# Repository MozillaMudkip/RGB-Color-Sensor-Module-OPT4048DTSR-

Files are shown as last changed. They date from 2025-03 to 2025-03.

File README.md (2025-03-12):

# RGB-Color-Sensor-Module-OPT4048DTSR-
Color Sensor Schematics, PCB and Code

This repository contains a collection of files that detail the creation of a RGB Color Sensor.

This color sensor module utilizes an OPT4048DTSR from Texas Instruments. This sensor is a high speed, high precision tristimulus XYZ color sensor which is able to perform high precision color to light digital conversion over an I2C interface. It is able to measure 4 channels, 3 of which match and recognize the CIE tristimulus spectra with the 4th being a wide band spectral responce. This sensor is paired with an LTW-C191TS5 from Lite-On to provide sufficient ambient white light so the OPT4048DTSR can measure color values from reflected light of the object to be sorted. This schematic and PCB was created in Altium Designer.

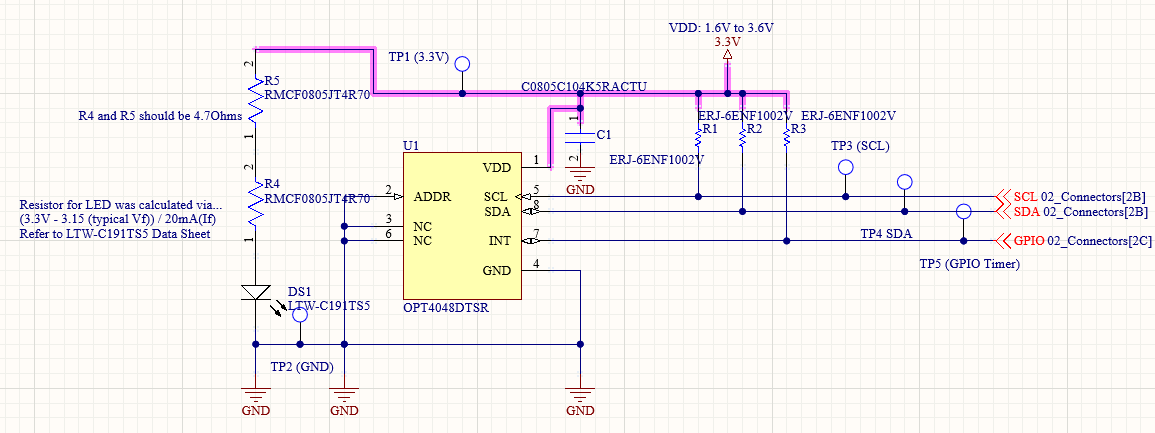
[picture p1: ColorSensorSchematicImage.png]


This particular sensor module was created to be a part of an automatic sorter, built as my Engineering Capstone Design project. Particularly, this sensor will be a part of the primary sensor array which, paired with an inductive sensor and an OpenCV camera system, will be able to look at an input object and determine aspects relating to its color, shape and material. The sorter will then sort the object with parameters specified by the user into one of many containers. 

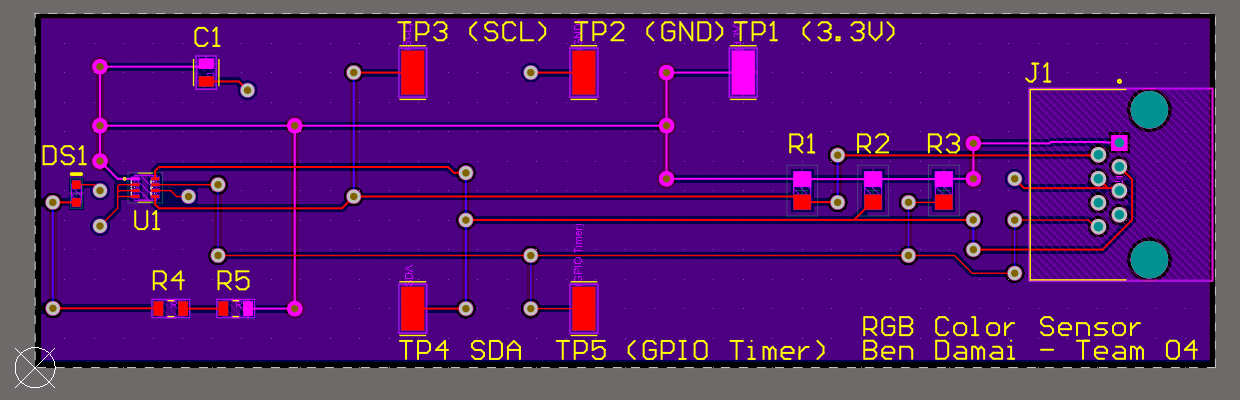
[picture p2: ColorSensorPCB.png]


The OPT4048DTSR and LED system takes in just a 3.3V input for power. Please note that the sensor has a minimum open air voltage range from 1.6V to 3.6V. 3.3V proved to be a convenient value for us as we use a 3.3 voltage source in numerous other portions of out project. For more information, please refer to the OPT4048DTSR datasheet which gives more specific allowances and typical setup and application. *Note to myself and others* - This partcular LED has a dot on the NEGATIVE side of the LED and not the positive. Caused me some issues while soldering and testing!

https://www.ti.com/lit/ds/symlink/opt4048.pdf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

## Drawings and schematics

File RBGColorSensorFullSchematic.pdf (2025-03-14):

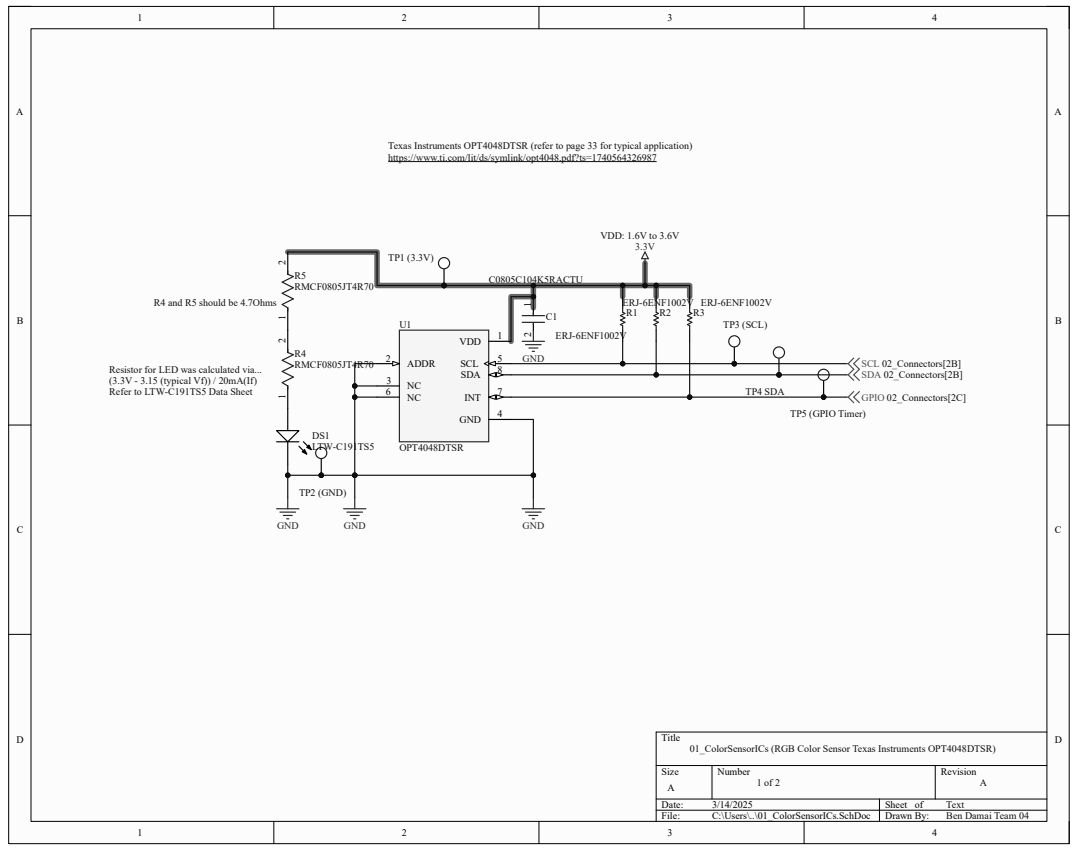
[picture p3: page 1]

Texas Instruments OPT4048DTSR (refer to page 33 for typical application)
https://www.ti.com/lit/ds/symlink/opt4048.pdf?ts=1740564326987

Resistor for LED was calculated via...
(3.3V - 3.15 (typical Vf)) / 20mA(If)

Title
01_ColorSensorICs (RGB Color Sensor Texas Instruments OPT4048DTSR)

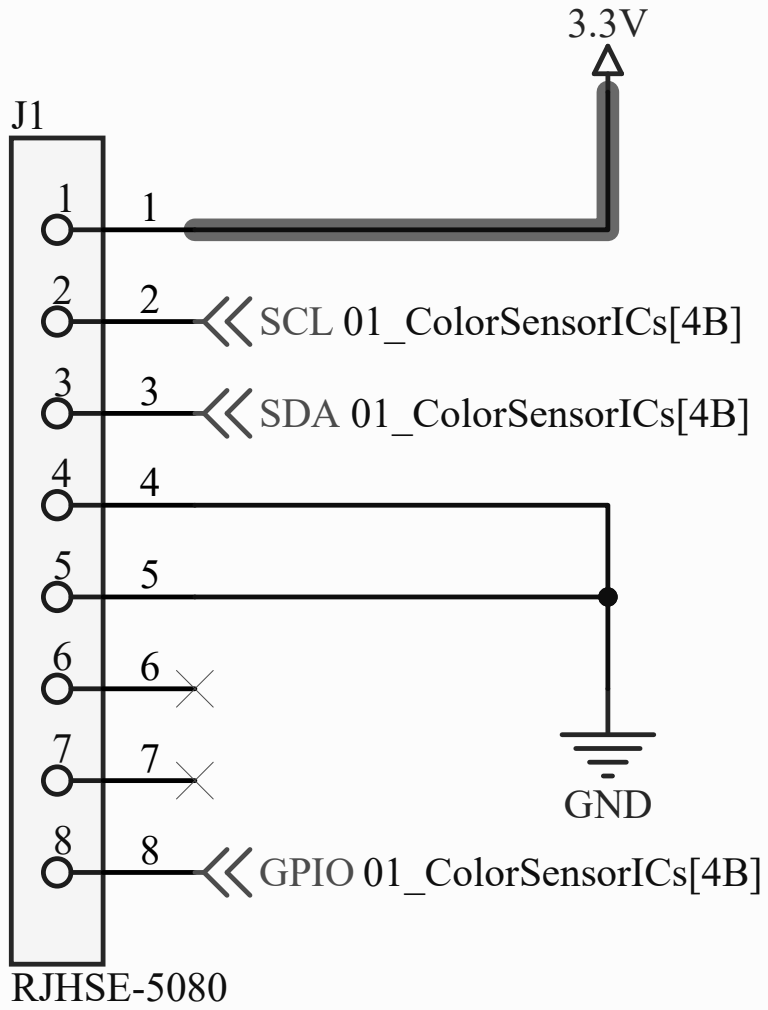
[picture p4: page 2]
Title; Size; Number; Revision; Date:; Sheet of; File:; C:\Users\..\02_Connectors.SchDoc; Drawn By:; 02_Connectors; Ben Damai Team 04; Text; RJHSE-5080; SCL 01_ColorSensorICs[4B]; SDA 01_ColorSensorICs[4B]; GPIO 01_ColorSensorICs[4B]; GND

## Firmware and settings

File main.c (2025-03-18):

#include "main.h"
#include "i2c.h"
#include "source/app_hw/task_console.h"
#include "source/app_hw/task_color_sensor.h"

int main(void) {
    cy_rslt_t rslt;
    rslt = cybsp_init();
    CY_ASSERT(rslt == CY_RSLT_SUCCESS);
    __enable_irq();

    i2c_init();
    /* Initialize FreeRTOS tasks */
    task_console_init();
    /* Initialize color sensor task */
    task_color_sensor_init();  
    /* Start scheduler to operate task functionality */ 
    vTaskStartScheduler();

    for (;;) { }
}

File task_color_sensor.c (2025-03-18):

#include "task_color_sensor.h"

/* Define I2C SDA and SCL pins */
#define COLOR_SENSOR_SDA    P9_0  
#define COLOR_SENSOR_SCL    P9_1 

#define OPT4048_I2C_ADDR  0x44  // I2C address with ADDR tied to GND (considered the default for this sensor)
#define OPT4048_REG_DATA  0x00  // Register to read color data
#define OPT4048_REG_CONFIG 0x0A // Sensor configuration register
/* FreeRTOS queue to send color data */
QueueHandle_t q_color_data;

static bool color_sensor_write_config(void) {
    uint8_t config_data[3] = {0x0A, 0x32, 0x38};  //Power on sensor and put into continuous operation
    uint8_t read_data[2];
    cy_rslt_t result;

    xSemaphoreTake(Semaphore_I2C, portMAX_DELAY); // Take I2C semaphore
    // Write to the configuration register
    result = cyhal_i2c_master_write(&i2c_master_obj, OPT4048_I2C_ADDR, config_data, 3, 0, true);
    //Delay to give sensor time to get ready for a read
    vTaskDelay(pdMS_TO_TICKS(500));
    //Read data from configuration register (for checking on oscilloscope)
    result = cyhal_i2c_master_read(&i2c_master_obj, OPT4048_I2C_ADDR, read_data, 2, 0, true);
    xSemaphoreGive(Semaphore_I2C); // Release I2C semaphore
    //Print out failure if we're given a failing read or write response
    if (result != CY_RSLT_SUCCESS) {
        task_print("Failed to write configuration register: 0x%04X\n", result); 
        return false;
    }
    return true;
}
/* Function to read from OPT4048 */
static bool color_sensor_read(uint8_t reg, uint8_t *data, uint8_t len) {     
    cy_rslt_t result;
    xSemaphoreTake(Semaphore_I2C, portMAX_DELAY); //Gain control of I2C bus

    //Write register address of the sensor
    result = cyhal_i2c_master_write(&i2c_master_obj, OPT4048_I2C_ADDR, &reg, 1, 0, true);   
    if (result != CY_RSLT_SUCCESS){
        xSemaphoreGive(Semaphore_I2C); //Return I2C bus on failure
        return false;
    }
    vTaskDelay(pdMS_TO_TICKS(500));
    //Read the data from the sensor
    result = cyhal_i2c_master_read(&i2c_master_obj, OPT4048_I2C_ADDR, data, len, 0, true);
    xSemaphoreGive(Semaphore_I2C); //Return I2C bus
    return (result == CY_RSLT_SUCCESS);
}

/* Color Sensor Task */
static void task_color_sensor(void *param) {
    /* Initialize the sensor by writing to the configuration register */
    if (!color_sensor_write_config()) {
        task_print("Failed to initialize OPT4048 sensor. Check I2C communication.\n");
        return; // Exit if initialization fails
    }
    
    while (1) {
        /* Wait before next read, avoids reading before sensor is ready */
        vTaskDelay(pdMS_TO_TICKS(1000));
    }
}

/* CLI Handler for 'colorsensor' command */
static BaseType_t cli_handler_colorsensor(
    char *pcWriteBuffer,
    size_t xWriteBufferLen,
    const char *pcCommandString)
{
    const char *pcParameter;
    BaseType_t xParameterStringLength, xReturn;
    color_data_t color_values;
    uint8_t raw_data[8];

    /* Get parameter string */
    pcParameter = FreeRTOS_CLIGetParameter(
        pcCommandString, 1, &xParameterStringLength);
    configASSERT(pcParameter);

    /* If we recieve the print command from the serial monitor... */
    if (strncmp(pcParameter, "print", xParameterStringLength) == 0) {
        //Read color sensor data 
        if (color_sensor_read(OPT4048_REG_DATA, raw_data, 8)) {    
            uint16_t x = (raw_data[0] << 8) | raw_data[1];
            uint16_t y = (raw_data[2] << 8) | raw_data[3];
            uint16_t z = (raw_data[4] << 8) | raw_data[5];
            uint16_t w = (raw_data[6] << 8) | raw_data[7];

            //Update color values
            color_values.red = x;
            color_values.green = y;
            color_values.blue = z;
            color_values.clear = w;

            /* Send data to queue */
            xQueueSend(q_color_data, &color_values, portMAX_DELAY);

            vTaskDelay(pdMS_TO_TICKS(500));
            /* Print out color data to serial monitor */
            task_print("X: %u, Y: %u, Z: %u, W: %u\n",
                       color_values.red, color_values.green,
                       color_values.blue, color_values.clear);
        }
    } 
    //In the event of any other input, give correct usage
    else {
        snprintf(pcWriteBuffer, xWriteBufferLen, "Invalid command. Use 'colorsensor print'.\n");
        xReturn = pdFALSE;
        return xReturn;
    }
    xReturn = pdFALSE;
    return xReturn;
}

/* The CLI command definition for the color sensor 
 User types in "colorsensor print" into serial monitor 
 to recieve printout of most recent color reading */
static const CLI_Command_Definition_t xColorSensor =
    {
        "colorsensor",
        "\r\ncolorsensor <print>\r\n Controls color sensor output.\r\n",
        cli_handler_colorsensor,
        1
    };

/* Initialization function for color sensor */
void task_color_sensor_init(void) {
    cy_rslt_t rslt;

    /* Create queue for color data */
    q_color_data = xQueueCreate(5, sizeof(color_data_t));
    configASSERT(q_color_data != NULL);

    /* Register CLI command */
    FreeRTOS_CLIRegisterCommand(&xColorSensor);
    
    /* Create FreeRTOS task */
    xTaskCreate(task_color_sensor, "Task_Color_Sensor", configMINIMAL_STACK_SIZE + 100, NULL, 2, NULL);
}

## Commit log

2025-03-10 Added schematic and PCB source files
    [01_ColorSensorICs.SchDoc, 02_Connectors.SchDoc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]
2025-03-10 Added images
    Added images for the schematic and PCB for easy viewing from repository!
2025-03-14 Added Full Schematic
2025-03-18 Added Color Sensor Task Code
    This version is more or less complete until we get a better sense of how we want to process our sensor information.
